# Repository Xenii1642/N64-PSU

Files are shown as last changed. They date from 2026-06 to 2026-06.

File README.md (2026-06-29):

<picture> <source media="(prefers-color-scheme: dark)" srcset="Images/logo-white.png" width="800">  </picture> 
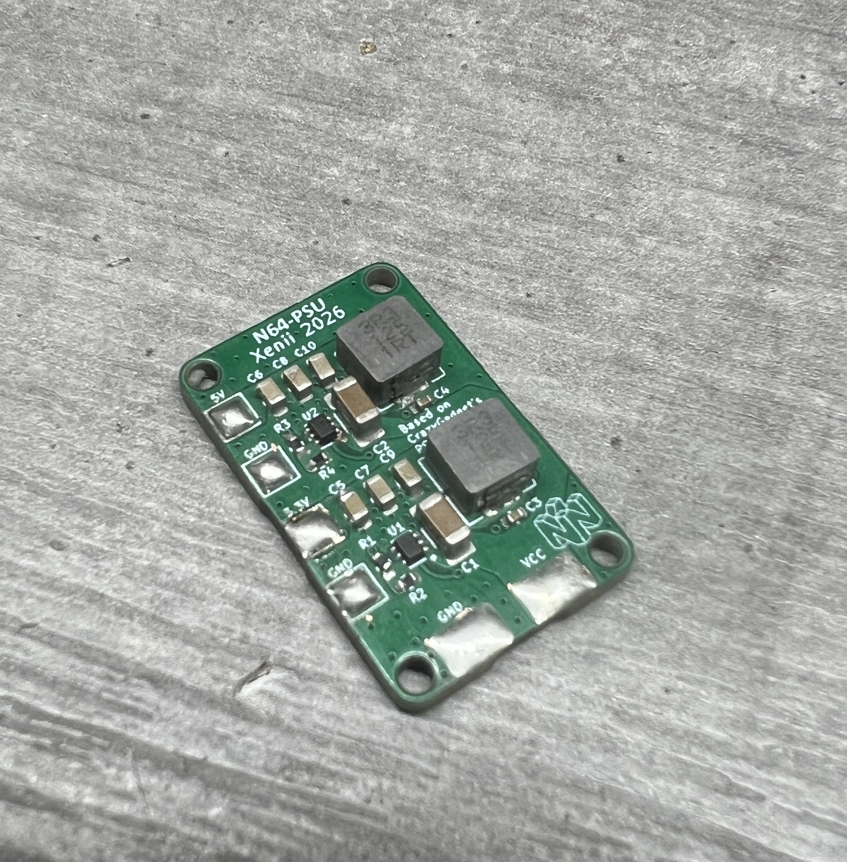
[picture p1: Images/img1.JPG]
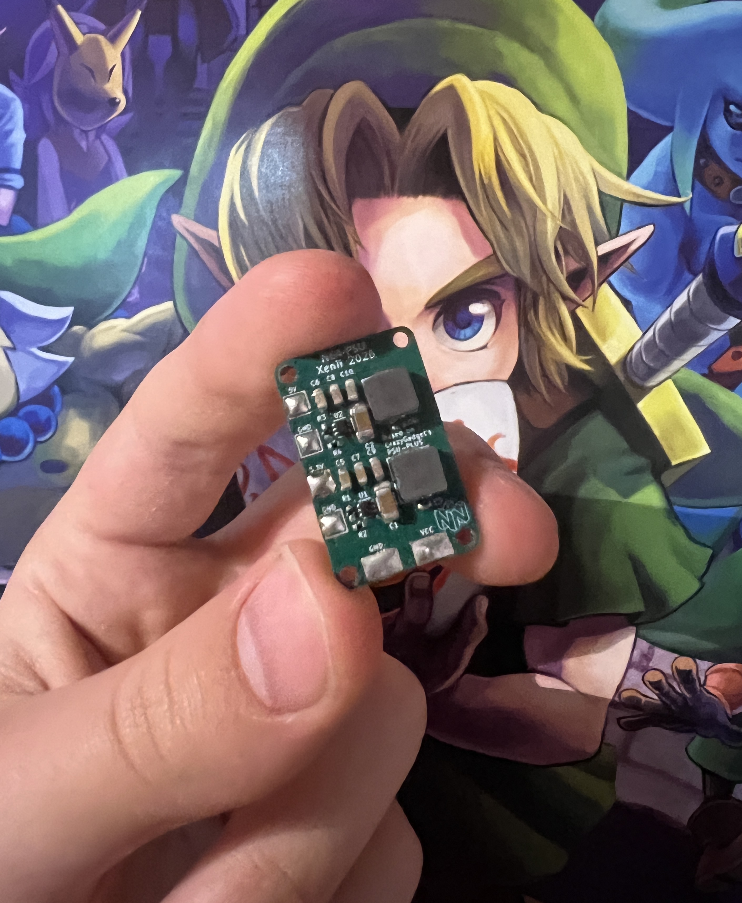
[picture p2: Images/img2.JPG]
   
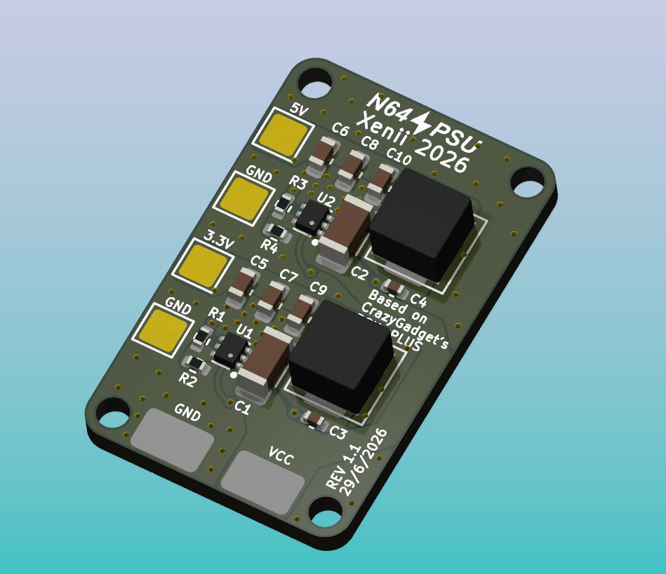
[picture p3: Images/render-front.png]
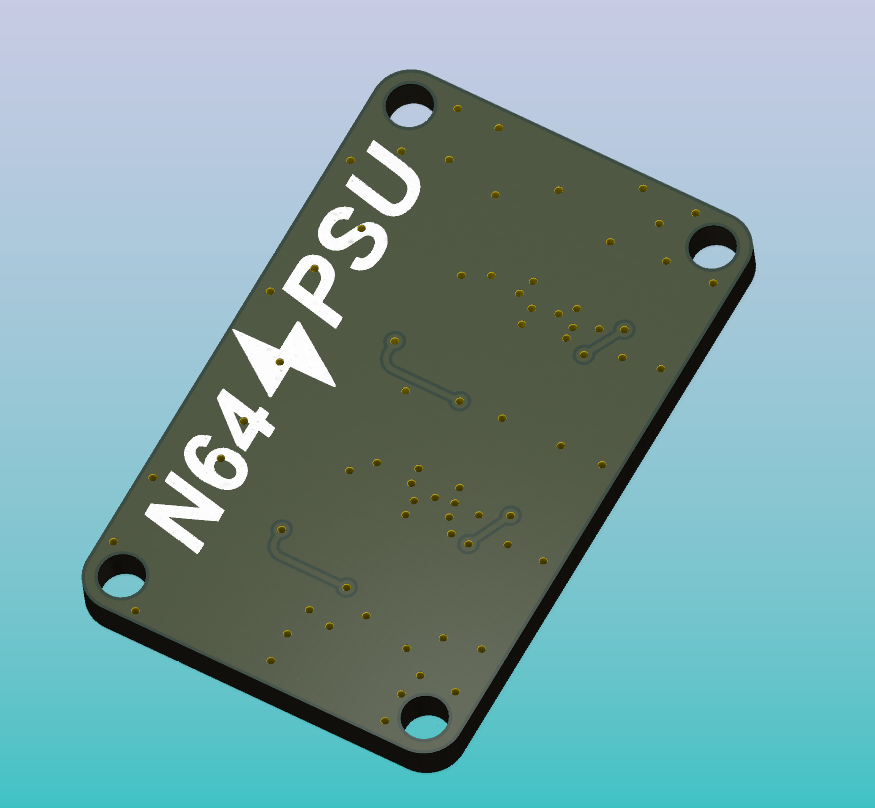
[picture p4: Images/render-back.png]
   

# Introduction 
The N64-PSU is a simple, compact, cheap and open-source Nintendo 64 Power Supply Unit. 
It can be used to power trimmed Nintendo 64 motherboard, or builds like the [Matterhorn 64 Core](https://github.com/Xenii1642/Matterhorn-64-CORE/)
This board is based on the [CrazyGadget's PSU-PLUS](https://github.com/CrazyGadgetMods/PSU-Plus). 
Further information can be found on this [BitBuilt Post](https://bitbuilt.net/forums/threads/n64-psu-tiny-and-open-source-nintendo-64-psu.7408/)

# Caracteristics 
- Input voltage from 6V to 18V
- 3.3V Regulator
- 5V Regulator
- Up to 3A per rail
- 16x25mm form factor
- Price under $5 per unit 

# Ordering
The PCB Gerbers files are available in the [Gerbers folder](https://github.com/Xenii1642/N64-PSU/tree/main/Gerbers) of this repository. 
They can be ordered through either [PCBway](https://www.pcbway.com/), [JLCPCB](https://www.jlcpcb.com/) or the manufacturer you want. 

Components are listed in the [BOM.pdf](https://github.com/Xenii1642/N64-PSU/blob/main/BOM.pdf) file, and can be ordered through [Digikey](https://www.digikey.com/)

# Connection Diagram
The N64-PSU can be connected to a Nintendo 64 motherboard as shown:
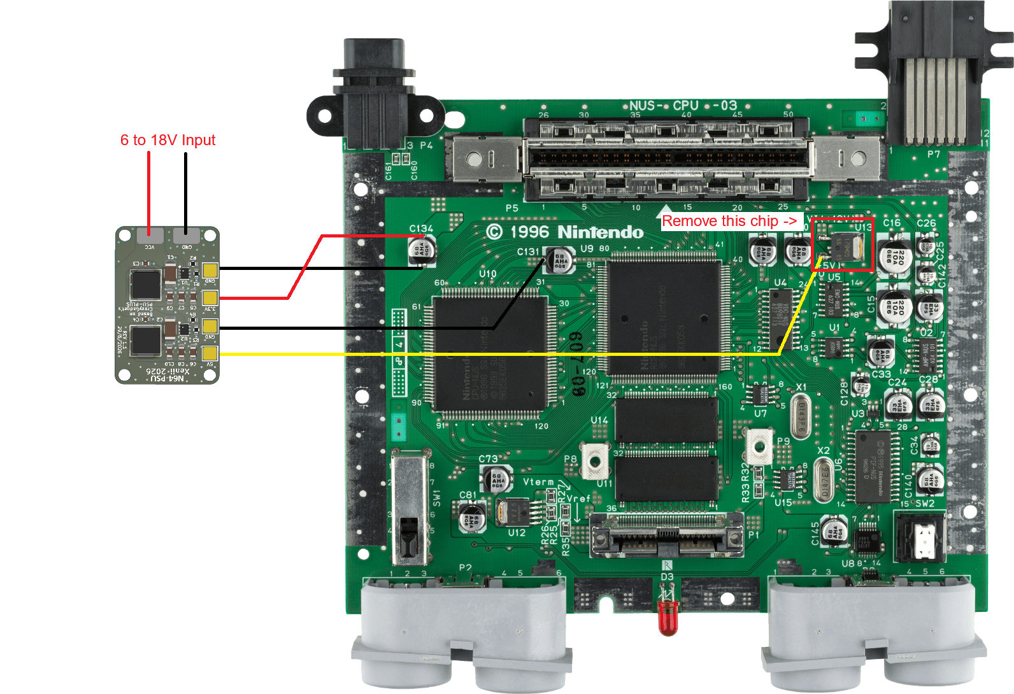
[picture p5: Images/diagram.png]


⚠️ It is highly recommended to remove the original 12 to 5V LDO (U13) ⚠️

⚠️ Never power the console by both the original power supply and the N64-PSU as the same time.
This will damage and destroy the voltage regulators of the N64-PSU. ⚠️

For further information, please take a look at the [N64 Trimming Guide](https://bitbuilt.net/forums/threads/the-advanced-n64-trimming-guide.3992/) on [Bitbuilt.net](https://bitbuilt.net/forums/)

Any modified versions of derivatives must also remain open-source under the same, unmodified license.
You must also properly credit the original creators when reusing or redistributing these files.

# Support
If you notice anything wrong with this design, please let me know! 
You can also reach to me for questions or general help, I'm always happy to help 👍

Thank you for your support and see you next time!

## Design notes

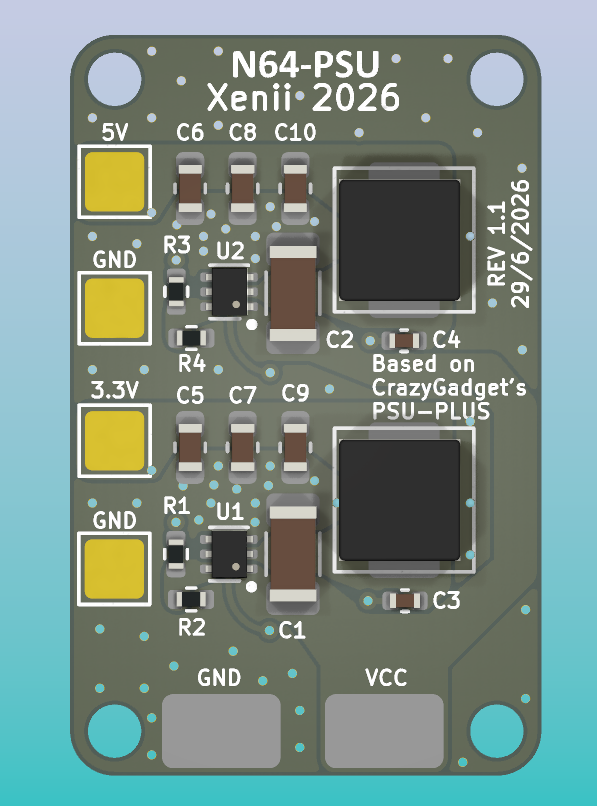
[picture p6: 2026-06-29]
Images/render-tiptop.png

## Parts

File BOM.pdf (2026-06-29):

# N64-PSU Bill Of Material

Reference | Quantity | Value | Description | Manufacter Part Number | Link
C1,C2 | 2 | 10uF | CAP CER 10UF 25V X7R 1206 | CL31B106KAHNNNE | https://www.digikey.com/en/products/detail/samsung-electro-mechanics/CL31B106KAHNNNE/3887462
C3,C4 | 2 | 100nF | CAP CER 0.1UF 25V X5R 0402 | CL05A104KA5NNNC | https://www.digikey.com/en/products/detail/samsung-electro-mechanics/CL05A104KA5NNNC/3886701
C5,C6,C7,C8,C9,C10 | 6 | 22uF | CAP CER 22UF 10V X5R 0603 | CL10A226MP8NUNE | https://www.digikey.com/en/products/detail/samsung-electro-mechanics/CL10A226MP8NUNE/3886932
L1,L2 | 2 | 3.3uH | FIXED IND 3.3UH 5A 38 MOHM SMD | PCMB053T-3R3MS | https://www.digikey.com/en/products/detail/susumu/PCMB053T-3R3MS/3672034
R1 | 1 | 31.6kΩ | RES 31.6K OHM 1% 1/16W 0402 | RC0402FR-0731K6L | https://www.digikey.com/en/products/detail/yageo/RC0402FR-0731K6L/5280975
R2,R4 | 2 | 10kΩ | RES 10K OHM 1% 1/16W 0402 | RC0402FR-1310KL | https://www.digikey.com/en/products/detail/yageo/RC0402FR-1310KL/12082404
R3 | 1 | 52.3kΩ | RES 52.3K OHM 1% 1/16W 0402 | RC0402FR-0752K3L | https://www.digikey.com/en/products/detail/yageo/RC0402FR-0752K3L/5281039
U1,U2 | 2 | AP62301Z6-7 | IC REG BUCK ADJ 3A SOT563 | AP62301Z6-7 | https://www.digikey.com/en/products/detail/diodes-incorporated/AP62301Z6-7/12349219

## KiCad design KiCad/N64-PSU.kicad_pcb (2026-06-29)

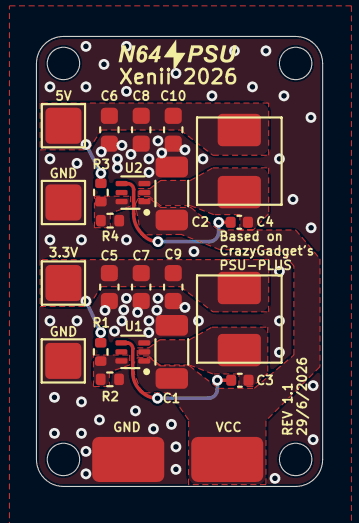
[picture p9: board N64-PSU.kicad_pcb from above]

Board: 2 copper layers, 15.9 x 25.0 mm, 24 parts (0 on the bottom side), 10 nets.

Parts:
3.3V: 3v3; TestPoint_Pad_2.0x2.0mm
5V: 5v; TestPoint_Pad_2.0x2.0mm
C1, C2: 10uF; C_1206_3216Metric
C3, C4: 100nF; C_0402_1005Metric
C5, C6, C7, C8, C9, C10: 22uF; C_0603_1608Metric
GND: GND; TestPoint_Pad_2.0x2.0mm
GND#2: GND; TestPoint_Pad_2.0x2.0mm
L1, L2: 3.3uH; Coil
R1: 31.6kΩ; R_0402_1005Metric
R2, R4: 10kΩ; R_0402_1005Metric
R3: 52.3kΩ; R_0402_1005Metric
TP1: VCC; PowerPad
TP2: GND; PowerPad
U1, U2: AP62301Z6-7; AP62301Z6

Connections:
GND: C1.1, C2.1, C5.2, C6.2, C7.2, C8.2, C9.2, C10.2, GND.1, GND#2.1, R2.2, R4.2, TP2.1, U1.3 (GND), U2.3 (GND)
unnamed: 3.3V.1, C5.1, C7.1, C9.1, L1.2, R1.1
unnamed: 5V.1, C6.1, C8.1, C10.1, L2.2, R3.1
unnamed: C3.1, U1.4 (BST)
unnamed: R1.2, R2.1, U1.6 (FB)
unnamed: C3.2, L1.1, U1.2 (SW)
unnamed: C4.1, U2.4 (BST)
unnamed: R3.2, R4.1, U2.6 (FB)
unnamed: C4.2, L2.1, U2.2 (SW)
VCC: C1.2, C2.2, TP1.1, U1.1 (VIN), U2.1 (VIN)
